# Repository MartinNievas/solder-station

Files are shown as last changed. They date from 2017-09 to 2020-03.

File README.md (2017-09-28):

# Solder Station

En este repositorio se encuentran los códigos y circuitos para fabricar una estación de soldado.

## Requerimientos

### Hardware
  - Arduino pro-mini
  - Punta de soldador Hakko 207 (repuesto) 
  - Fuente 12V@10A
### Software
  - Para compilar y cargar al arduino [platformio](http://platformio.org/).

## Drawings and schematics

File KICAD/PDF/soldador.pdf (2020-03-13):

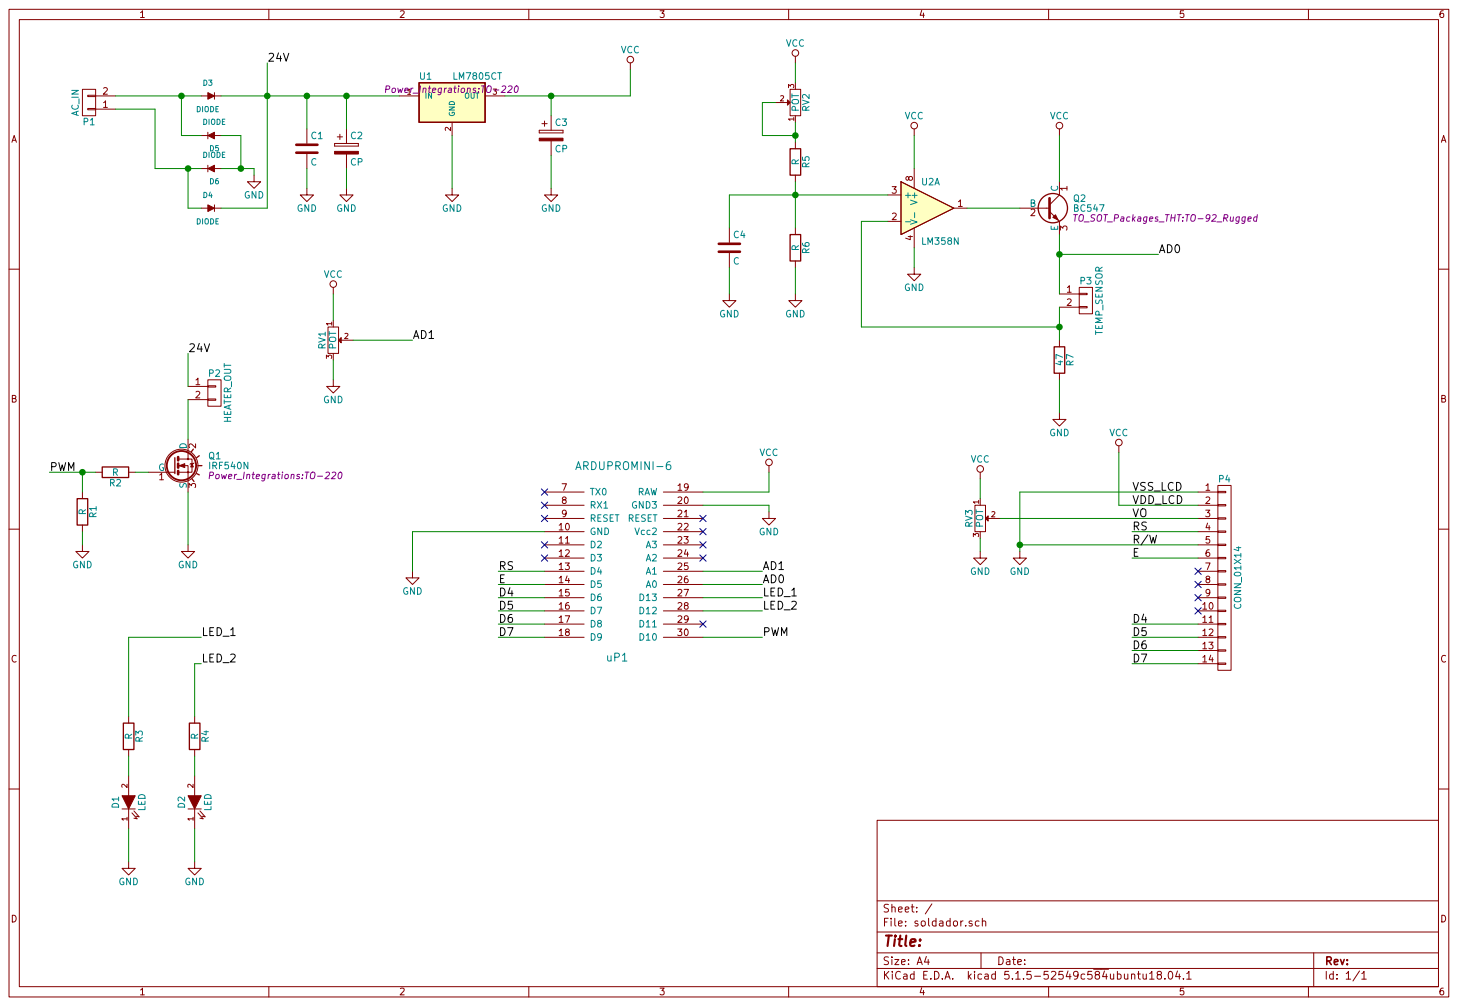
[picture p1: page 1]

3 POT RV2 VCC GND GND
VCC 47R7 C

Id: 1/1 Title: File: soldador.sch Sheet: / RR4

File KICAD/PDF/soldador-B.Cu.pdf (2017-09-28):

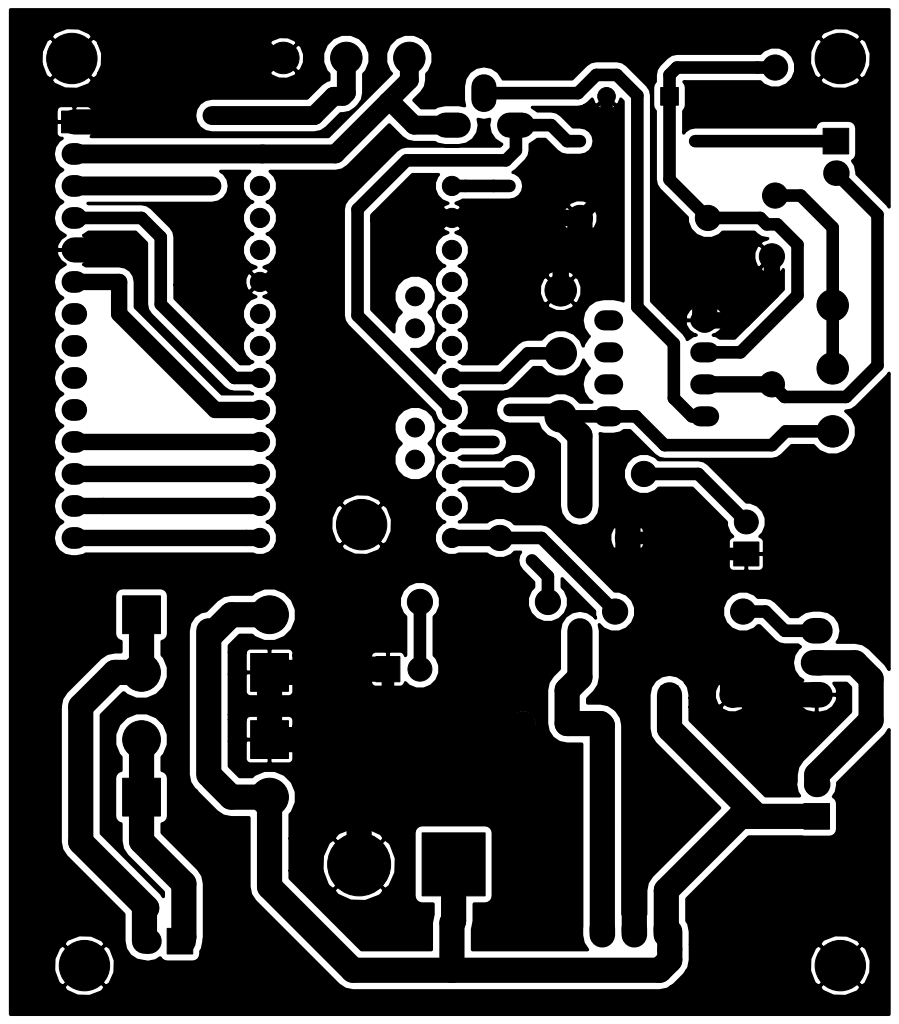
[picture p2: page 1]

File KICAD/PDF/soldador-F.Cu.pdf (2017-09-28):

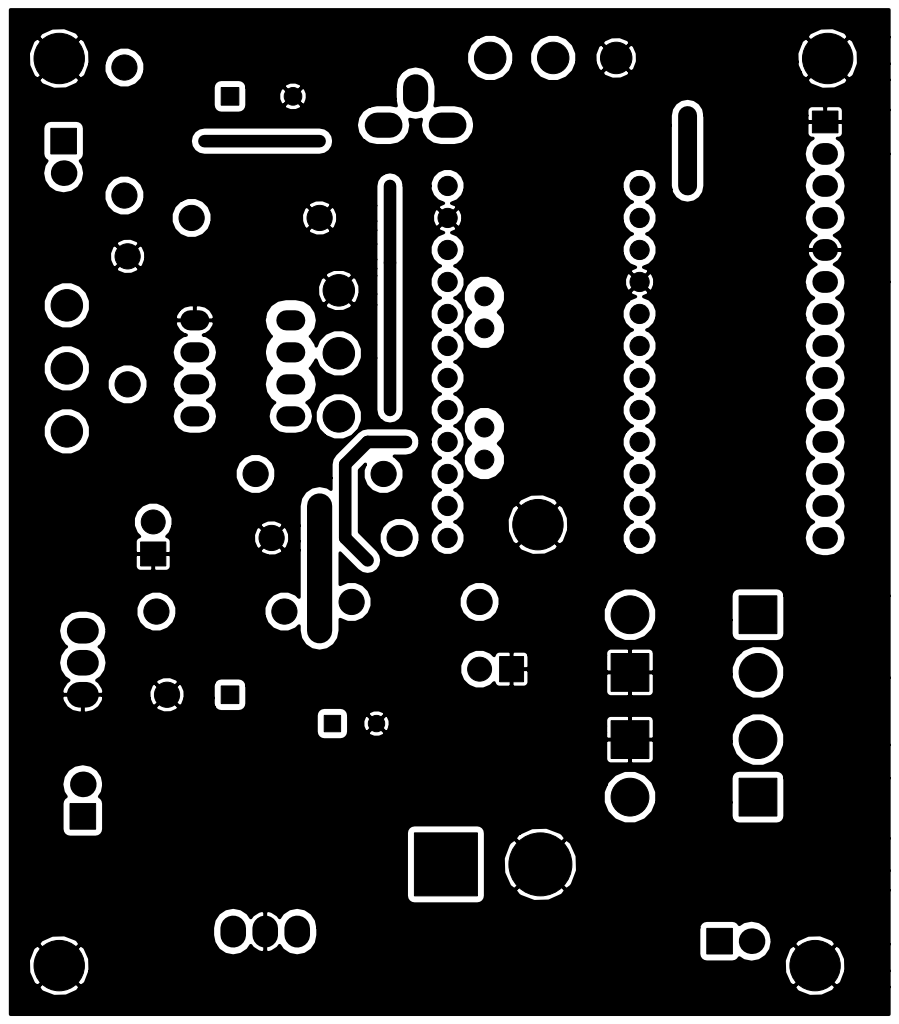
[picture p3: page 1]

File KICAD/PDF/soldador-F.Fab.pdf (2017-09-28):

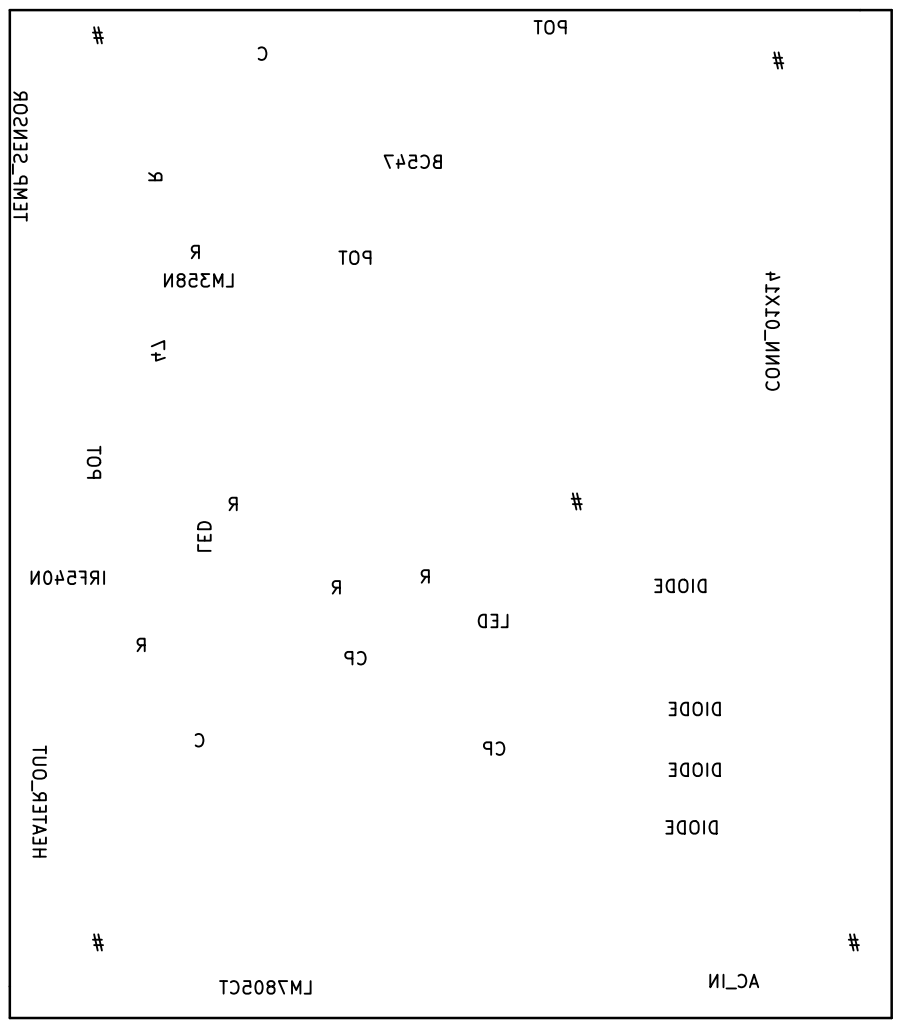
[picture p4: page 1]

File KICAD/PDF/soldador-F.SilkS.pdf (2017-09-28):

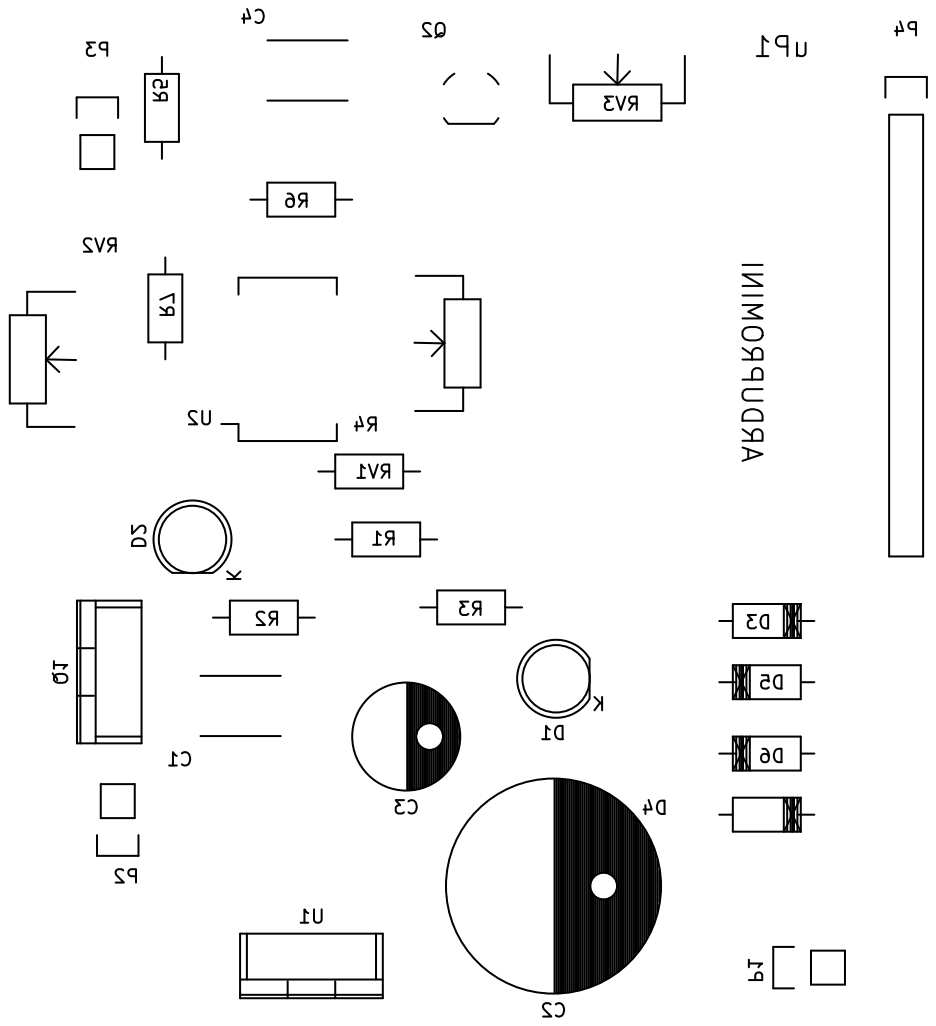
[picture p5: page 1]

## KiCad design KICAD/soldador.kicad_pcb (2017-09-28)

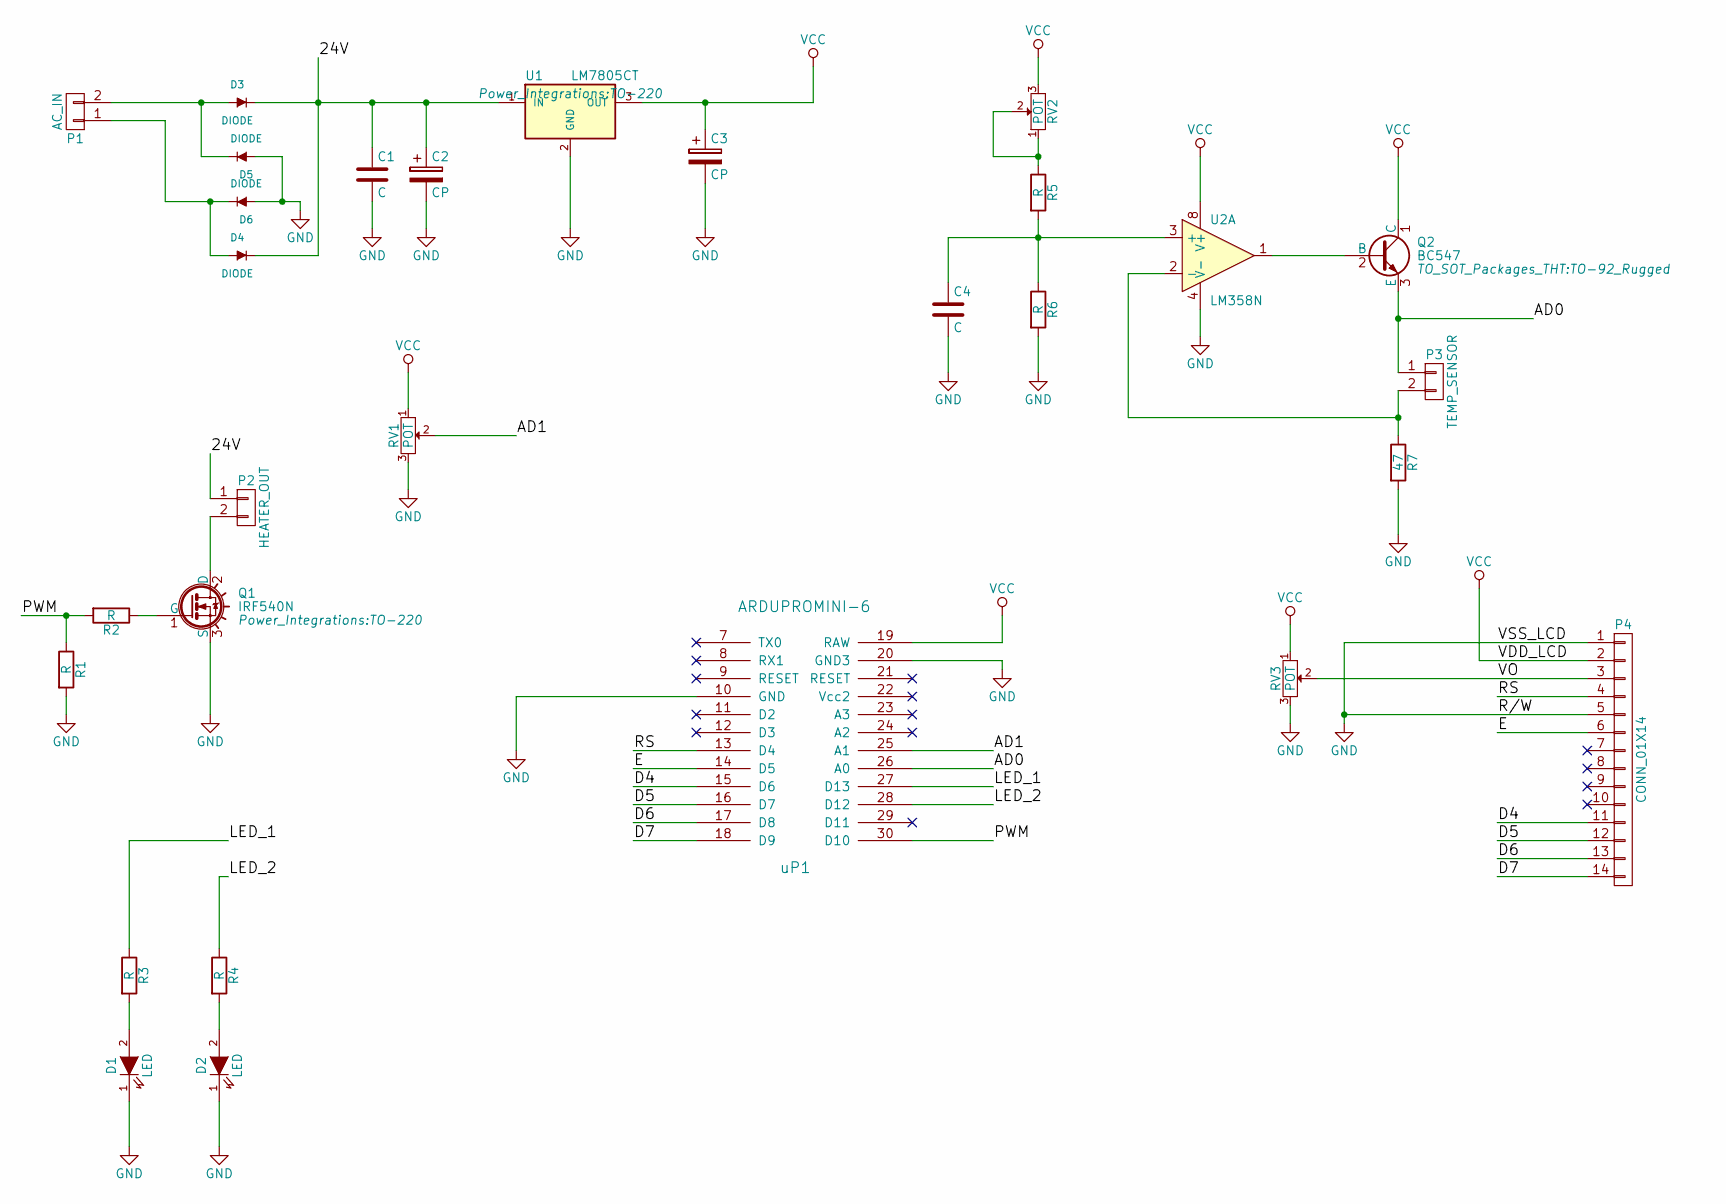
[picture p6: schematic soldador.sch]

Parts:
C1, C4: C; C_Disc_D6_P5
C2: CP; C_Radial_D16_L25_P7.5
C3: CP; C_Radial_D8_L11.5_P3.5
D1, D2: LED; LED-5MM
D3, D4, D5, D6: DIODE; Diode_DO-41_SOD81_Horizontal_RM10
P1: AC_IN; Pin_Header_Straight_1x02
P2: HEATER_OUT; Pin_Header_Straight_1x02
P3: TEMP_SENSOR; Pin_Header_Straight_1x02
P4: CONN_01X14; Pin_Header_Straight_1x14
Q1: IRF540N; TO-220
Q2: BC547; TO-92_Rugged
R1, R2, R3, R4, R5, R6: R; Resistor_Horizontal_RM10mm
R7: 47; Resistor_Horizontal_RM10mm
RV1, RV2, RV3: POT; Potentiometer_WirePads_largePads
U1: LM7805CT; TO-220
U2: LM358N; DIP-8_W7.62mm_LongPads
uP1: ARDUPROMINI-6; ArduProMini-6

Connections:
/24V: C1.1, C2.1, D3.2 (K), D4.2 (K), P2.1, U1.1 (IN)
/AD0: P3.1, Q2.3 (E), uP1.26 (A0)
/AD1: RV1.2, uP1.25 (A1)
/D4: P4.11, uP1.15 (D6)
/D5: P4.12, uP1.16 (D7)
/D6: P4.13, uP1.17 (D8)
/D7: P4.14, uP1.18 (D9)
/E: P4.6, uP1.14 (D5)
/LED_1: R3.1, uP1.27 (D13)
/LED_2: R4.1, uP1.28 (D12)
/PWM: R1.1, R2.2, uP1.30 (D10)
/RS: P4.4, uP1.13 (D4)
/VO: P4.3, RV3.2
GND: C1.2, C2.2, C3.2, C4.2, D1.1 (K), D2.1 (K), D5.1 (A), D6.1 (A), P4.1, P4.5, Q1.3 (S), R1.2, R6.2, R7.2, RV1.3, RV3.3, U1.2 (GND), U2.4 (V-), uP1.10 (GND), uP1.20 (GND3); also elsewhere on the board
unnamed: C4.1, R5.2, R6.1, U2.3 (+)
unnamed: D1.2 (A), R3.2
unnamed: D2.2 (A), R4.2
unnamed: D3.1 (A), D5.2 (K), P1.2
unnamed: D4.1 (A), D6.2 (K), P1.1
unnamed: P2.2, Q1.2 (D)
unnamed: P3.2, R7.1, U2.2 (-)
unnamed: Q1.1 (G), R2.1
unnamed: Q2.2 (B), U2.1
unnamed: R5.1, RV2.1, RV2.2
VCC: C3.1, P4.2, Q2.1 (C), RV1.1, RV2.3, RV3.1, U1.3 (OUT), U2.8 (V+), uP1.19 (RAW)

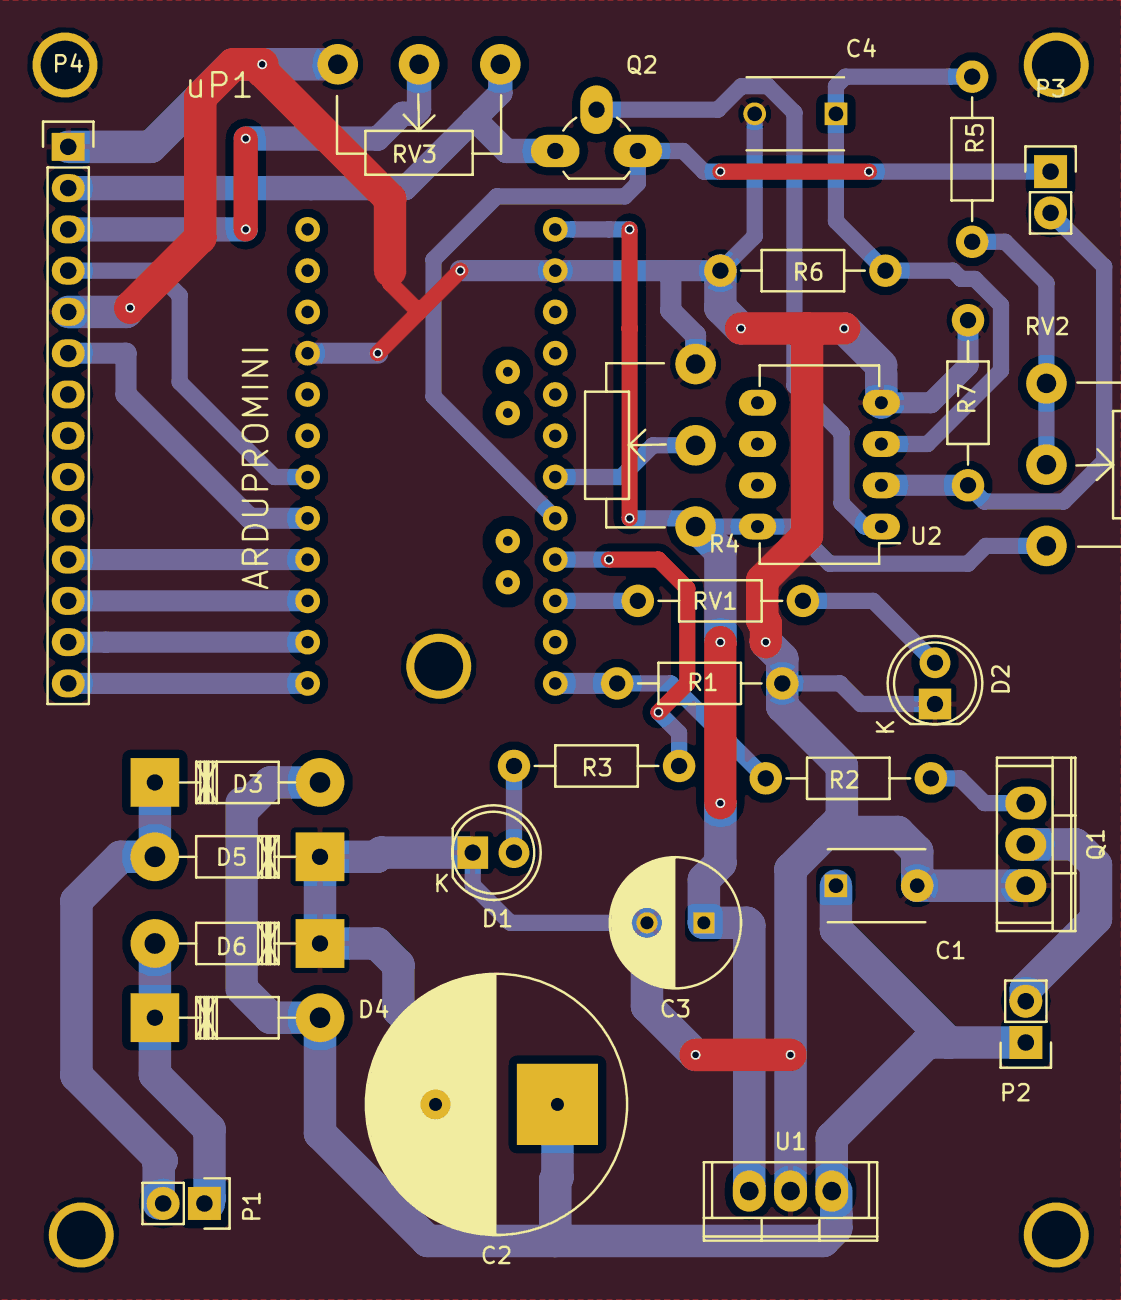
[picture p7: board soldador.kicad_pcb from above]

Board: 2 copper layers, 34 parts (0 on the bottom side), 25 nets.

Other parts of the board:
 : #; SolderWirePad_single_2mmDrill
 #2,  #3,  #4,  #5: #; SolderWirePad_single_2mmDrill

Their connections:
GND: ., #2., #3., #4., #5.; also elsewhere on the board

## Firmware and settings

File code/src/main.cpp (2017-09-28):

#include <Arduino.h>

#include <PID_v1.h>
#define LED1 14
#define LED2 15


double val1, val2;

//Define Variables we'll be connecting to
double Setpoint, Input, Output;

//Specify the links and initial tuning parameters
double Kp=1, Ki=6, Kd=2;

PID myPID(&Input, &Output, &Setpoint, Kp, Ki, Kd, DIRECT);

void setup() {
  Serial.begin(115200);
  pinMode(10, OUTPUT);
  pinMode(LED1, OUTPUT);
  pinMode(LED2, OUTPUT);
  myPID.SetMode(AUTOMATIC);
  Setpoint = 50;
  digitalWrite(LED1,HIGH);
  digitalWrite(LED2,HIGH);
}

void loop() {

val1 = analogRead(A1)/2;    // read the input pin
val2 = analogRead(A2);    // read the input pin

Setpoint = val1;
Serial.print(Setpoint);Serial.print("\t"); 

Input = val2*0.93-266.16;

Serial.print(Input);Serial.print("\t"); 

//if (Input < Setpoint)
//  digitalWrite(LED1,LOW);
//else
//  digitalWrite(LED1,HIGH);

if (Input > (Setpoint - 10) && Input < (Setpoint + 10))
{ 
  digitalWrite(LED1,LOW);
  digitalWrite(LED2,HIGH);

}
else
{
  digitalWrite(LED1,HIGH);
  digitalWrite(LED2,LOW);
}
myPID.Compute();

Serial.print(Output); Serial.print("\t"); 
analogWrite(10, Output); 



Serial.print(val1);             // debug value
Serial.print("\t");             // debug value
Serial.println(val2);             // debug value

}

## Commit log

2017-09-28 Electrónica. Circuitos y esquemáticos
    [soldador.kicad_pcb, soldador.sch]
2017-09-28 código para arduino pro-mini
